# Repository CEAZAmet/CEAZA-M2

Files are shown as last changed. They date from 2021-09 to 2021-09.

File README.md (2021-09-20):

# Welcome to CEAZA-M2!
Prototyping board for CEAZA MEGA system.
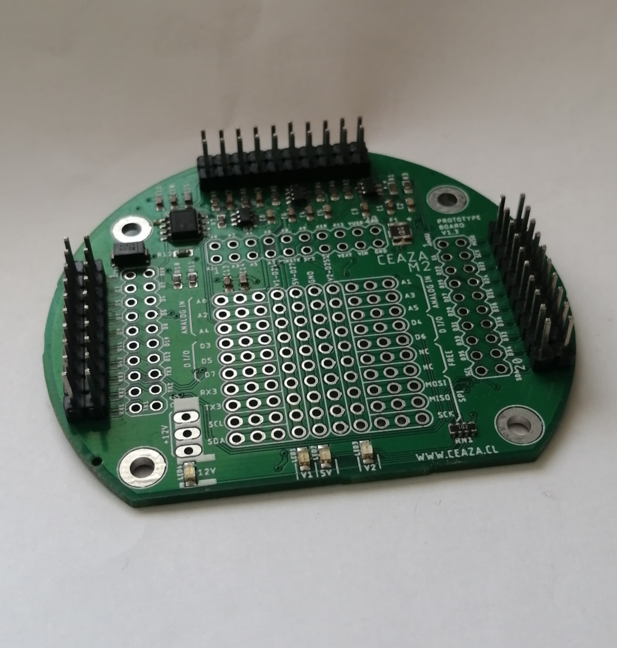
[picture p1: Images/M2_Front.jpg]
CEAZA M2 Board


# What is the CEAZA-M2?
Is a prototyping board with a firmware controlled +5V dedicated step-down power supply and controlled Vin pin for CEAZA MEGA system.
The board give you access to some pins as a PCB breadboard format, ready to solder any module or device.
Furthermore the board have a duplicate I/O expansion terminals to give you direct access to any of its pins.
Whith CEAZA M2 board you can easyly integrate any device to CEAZA MEGA system without any other customized board.

## Documentation
A comprehensive documentation for well undertand, use or modify the CEAZA M2 board is available in our Wiki. In adition, we share with you the schematics diagrams, adns Arduino example codes.

## Quickstart guide
Plan your electronic conection to your device, solder the necesay wires to connect your devices in the M2 board.
Install the M2 board in the CEAZA MEGA's bottom, make certain connection throuhg the boards by three 2 x 10 pin header terminals is rigth. Plug the battery and solar panel cables in the respective board terminal. be careful to avoid swap both plugs, due they are the same type of terminals. Connect the CEAZA MEGA main board system to the host PC by mini-USB connector, open the Arduino ide software, select the Arduino Mega board and the correspondign COM port.
Open any of examples scketches and upload to the board.
### WARNING!
Be careful with your breadboard conections due exist a posibility of a shortcircuit of the power supply acces in the breadboard. 
A 1A PTC Resettable fuse is placed in the main electric supply to the board (VIN pin od I/O expansion terminal) for extra electric protection.

# Contact and support
For all kinds of inquiries, please contact me to my e-mail address: adrian.gallardo@ceaza.cl

# Contributing
You are welcome to contribute to the development or improvement of M2 hardware design or example application codes. Feel free to submit a new pull request via github.

# Academic Context

# Licensing

# Disclaimer
Use M2 board and examples code at your own risk. We do not encourage any malicious use of our board.

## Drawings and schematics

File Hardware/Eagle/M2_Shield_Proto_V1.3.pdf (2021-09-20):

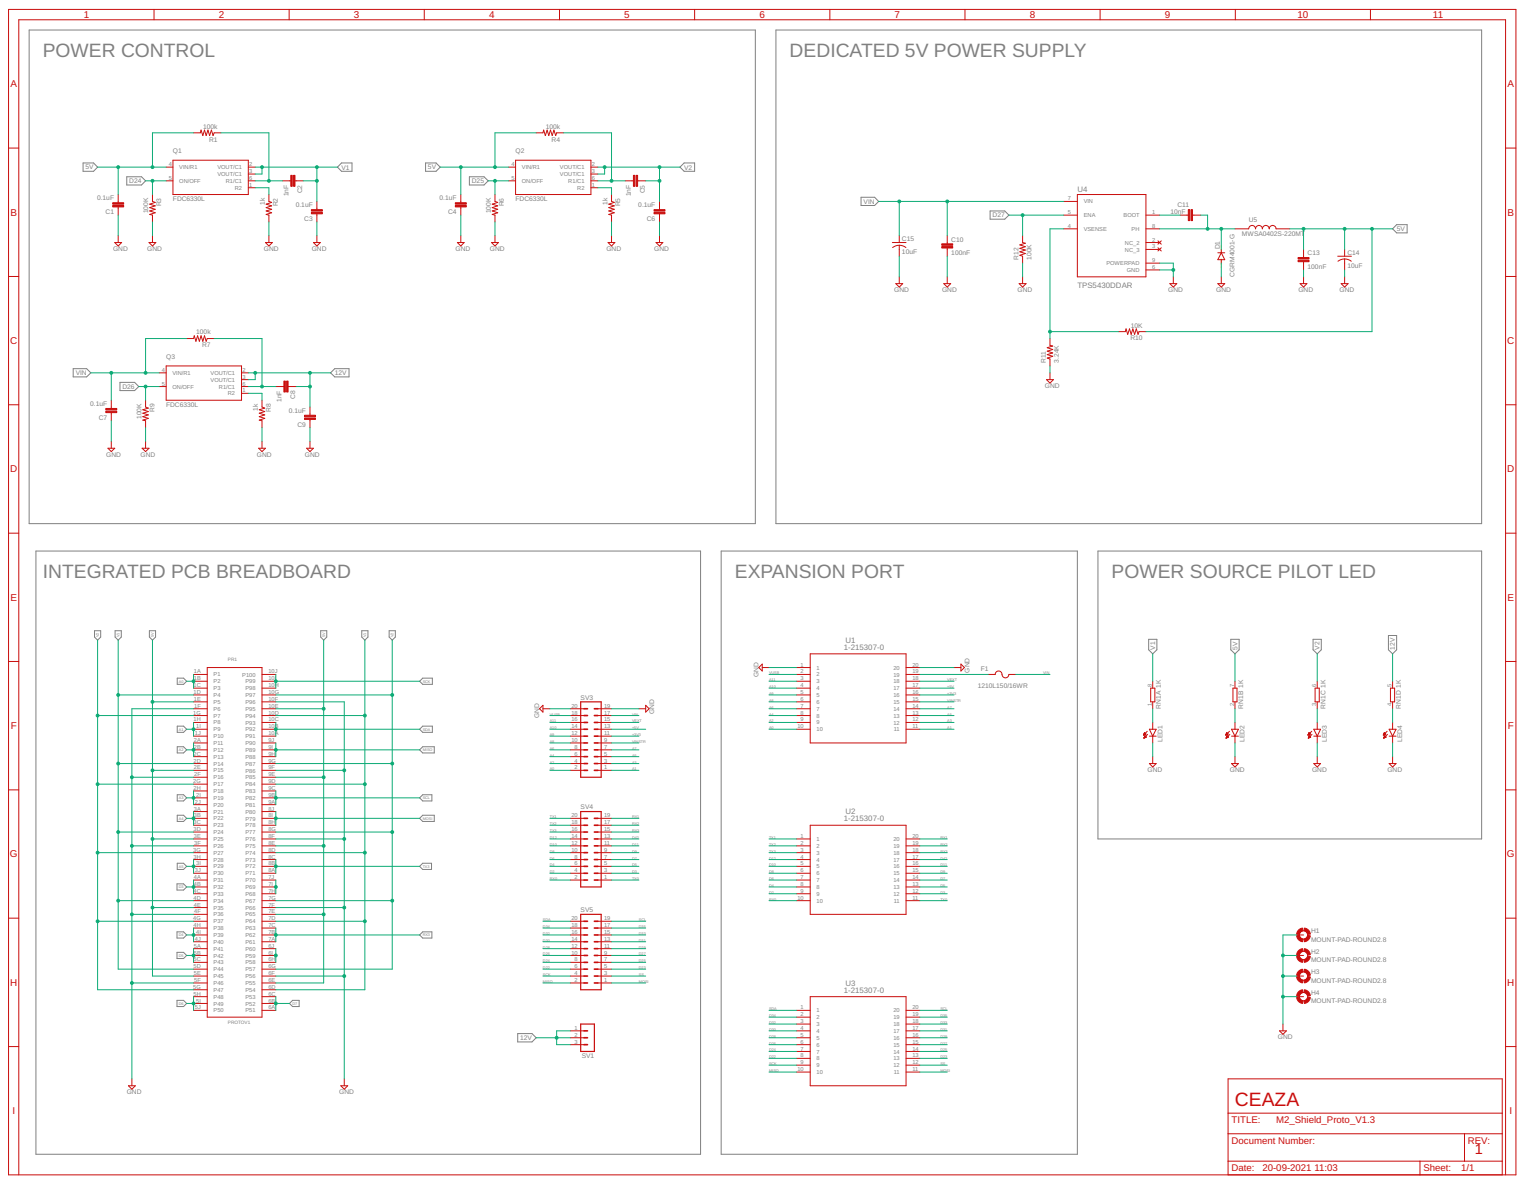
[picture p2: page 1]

MOUNT-PAD-ROUND2.8 MOUNT-PAD-ROUND2.8

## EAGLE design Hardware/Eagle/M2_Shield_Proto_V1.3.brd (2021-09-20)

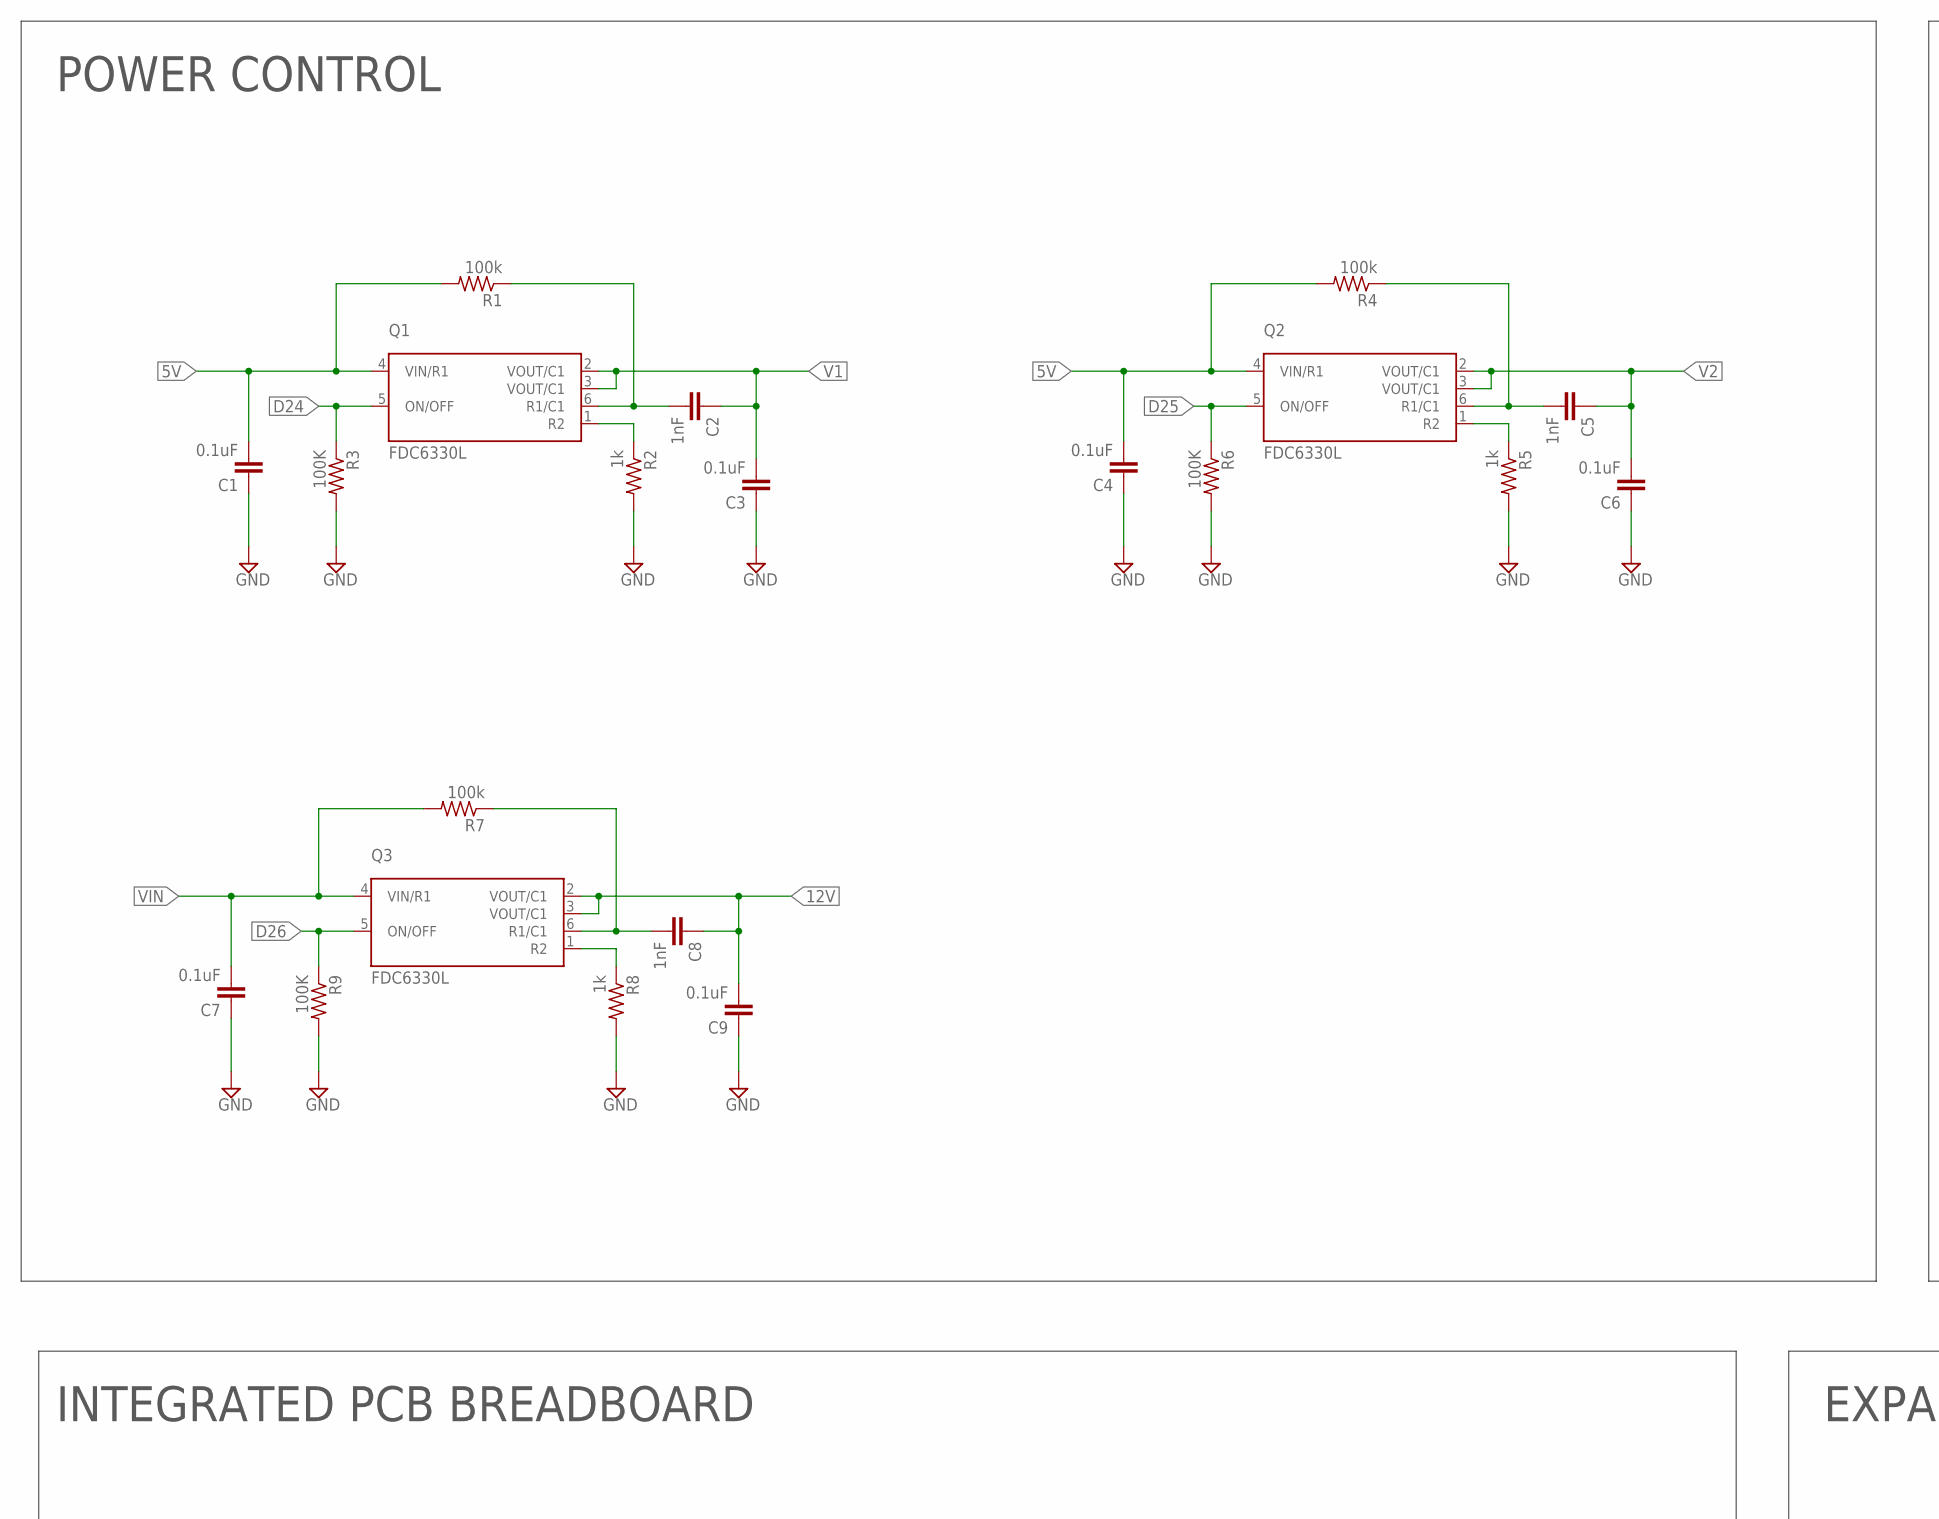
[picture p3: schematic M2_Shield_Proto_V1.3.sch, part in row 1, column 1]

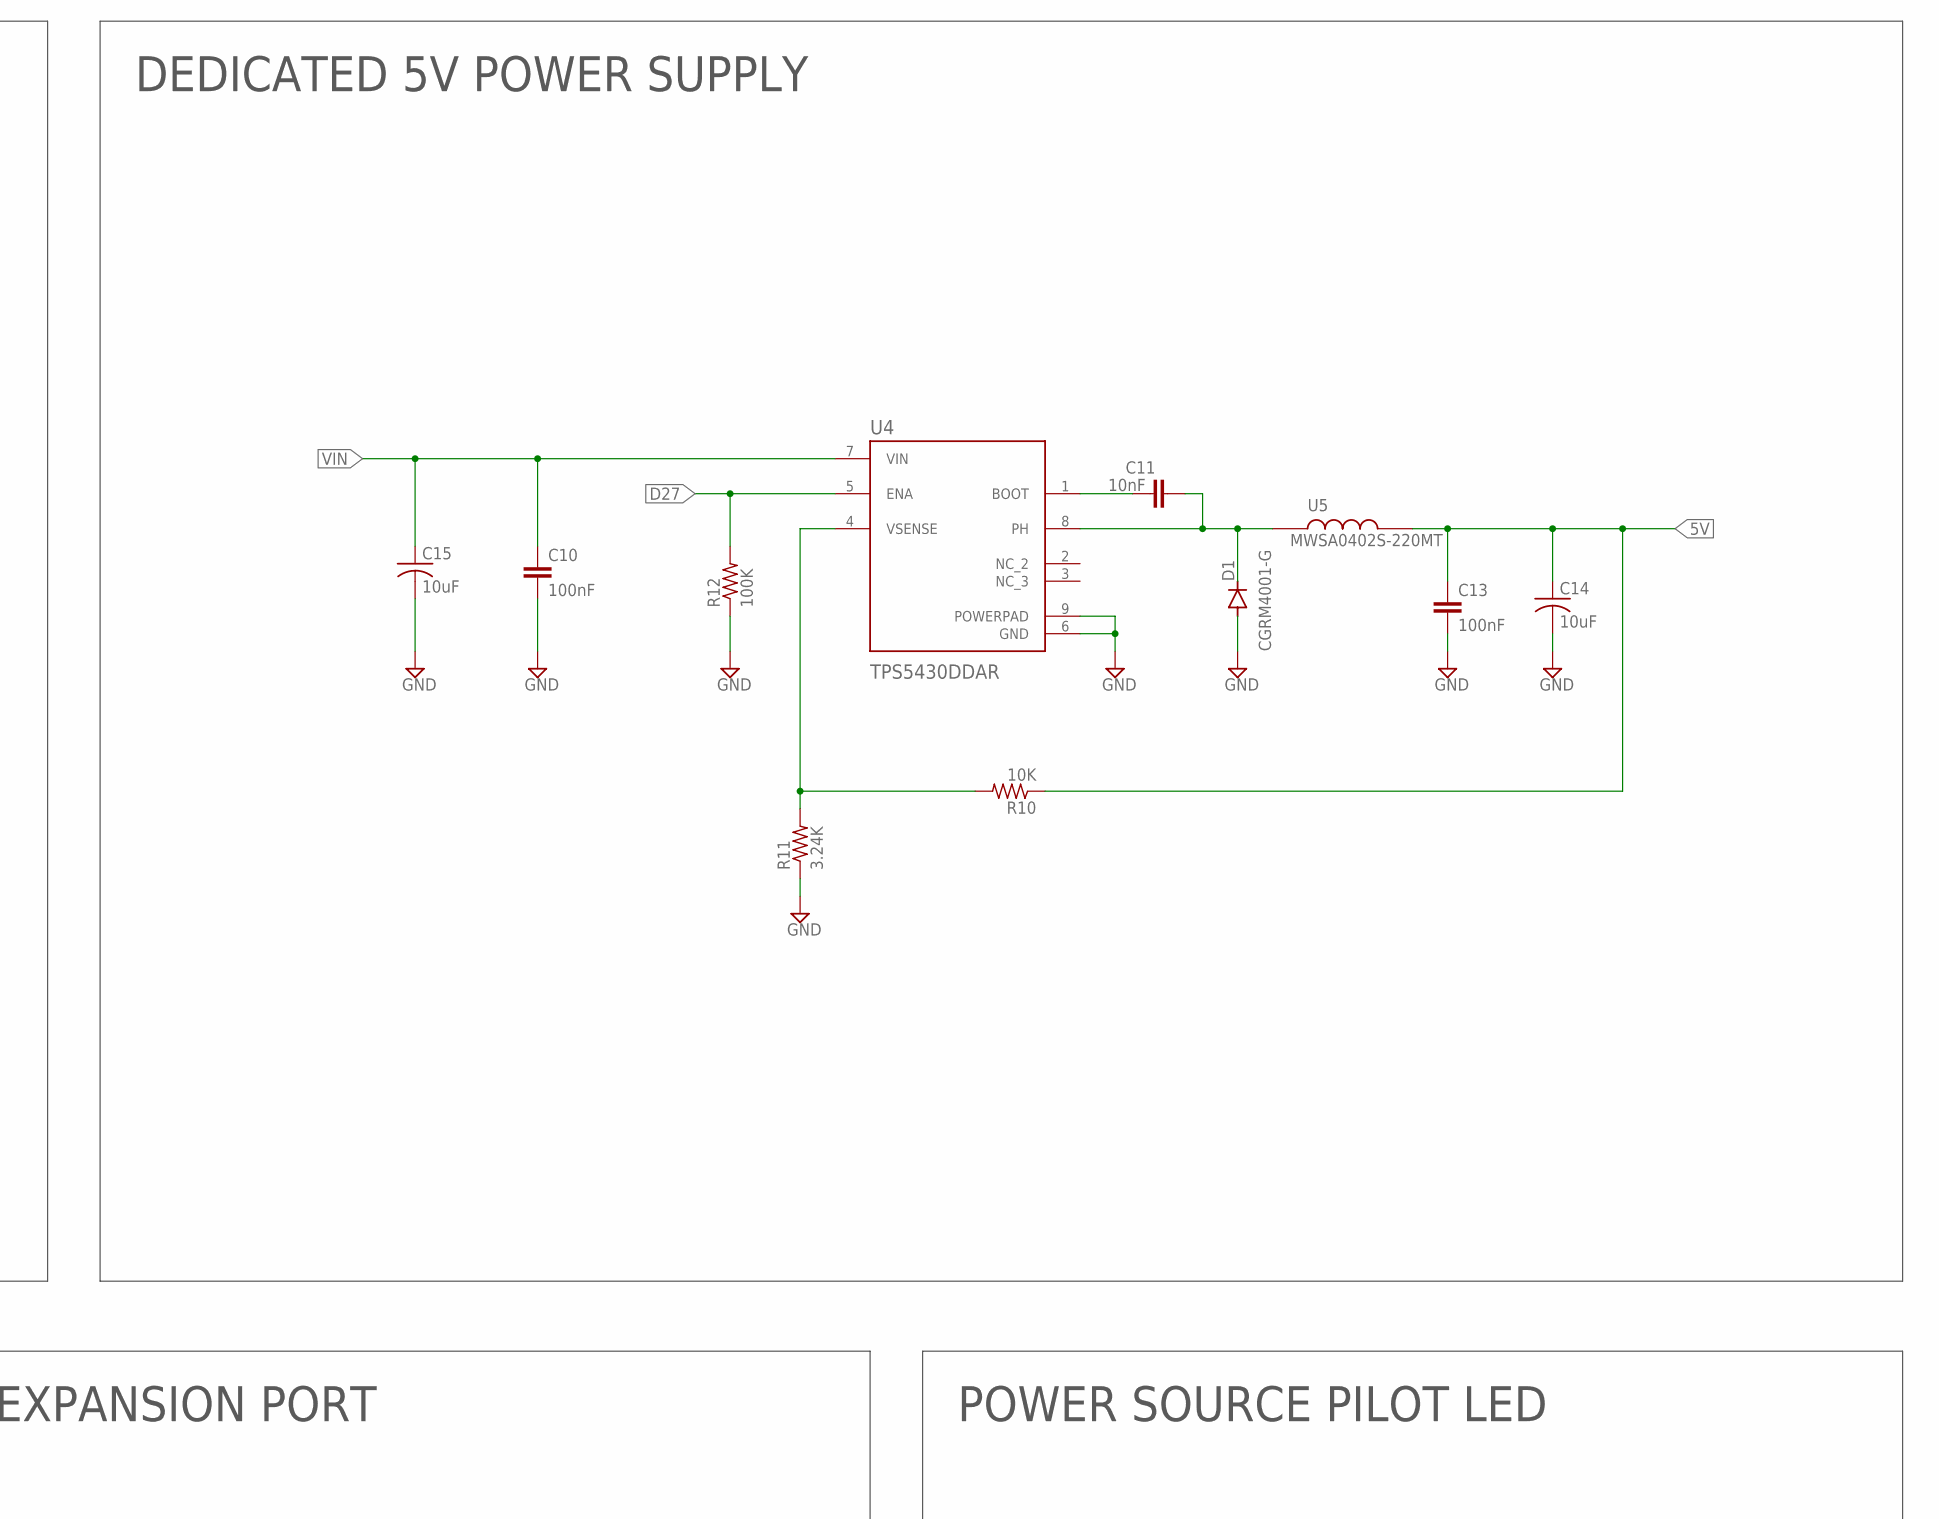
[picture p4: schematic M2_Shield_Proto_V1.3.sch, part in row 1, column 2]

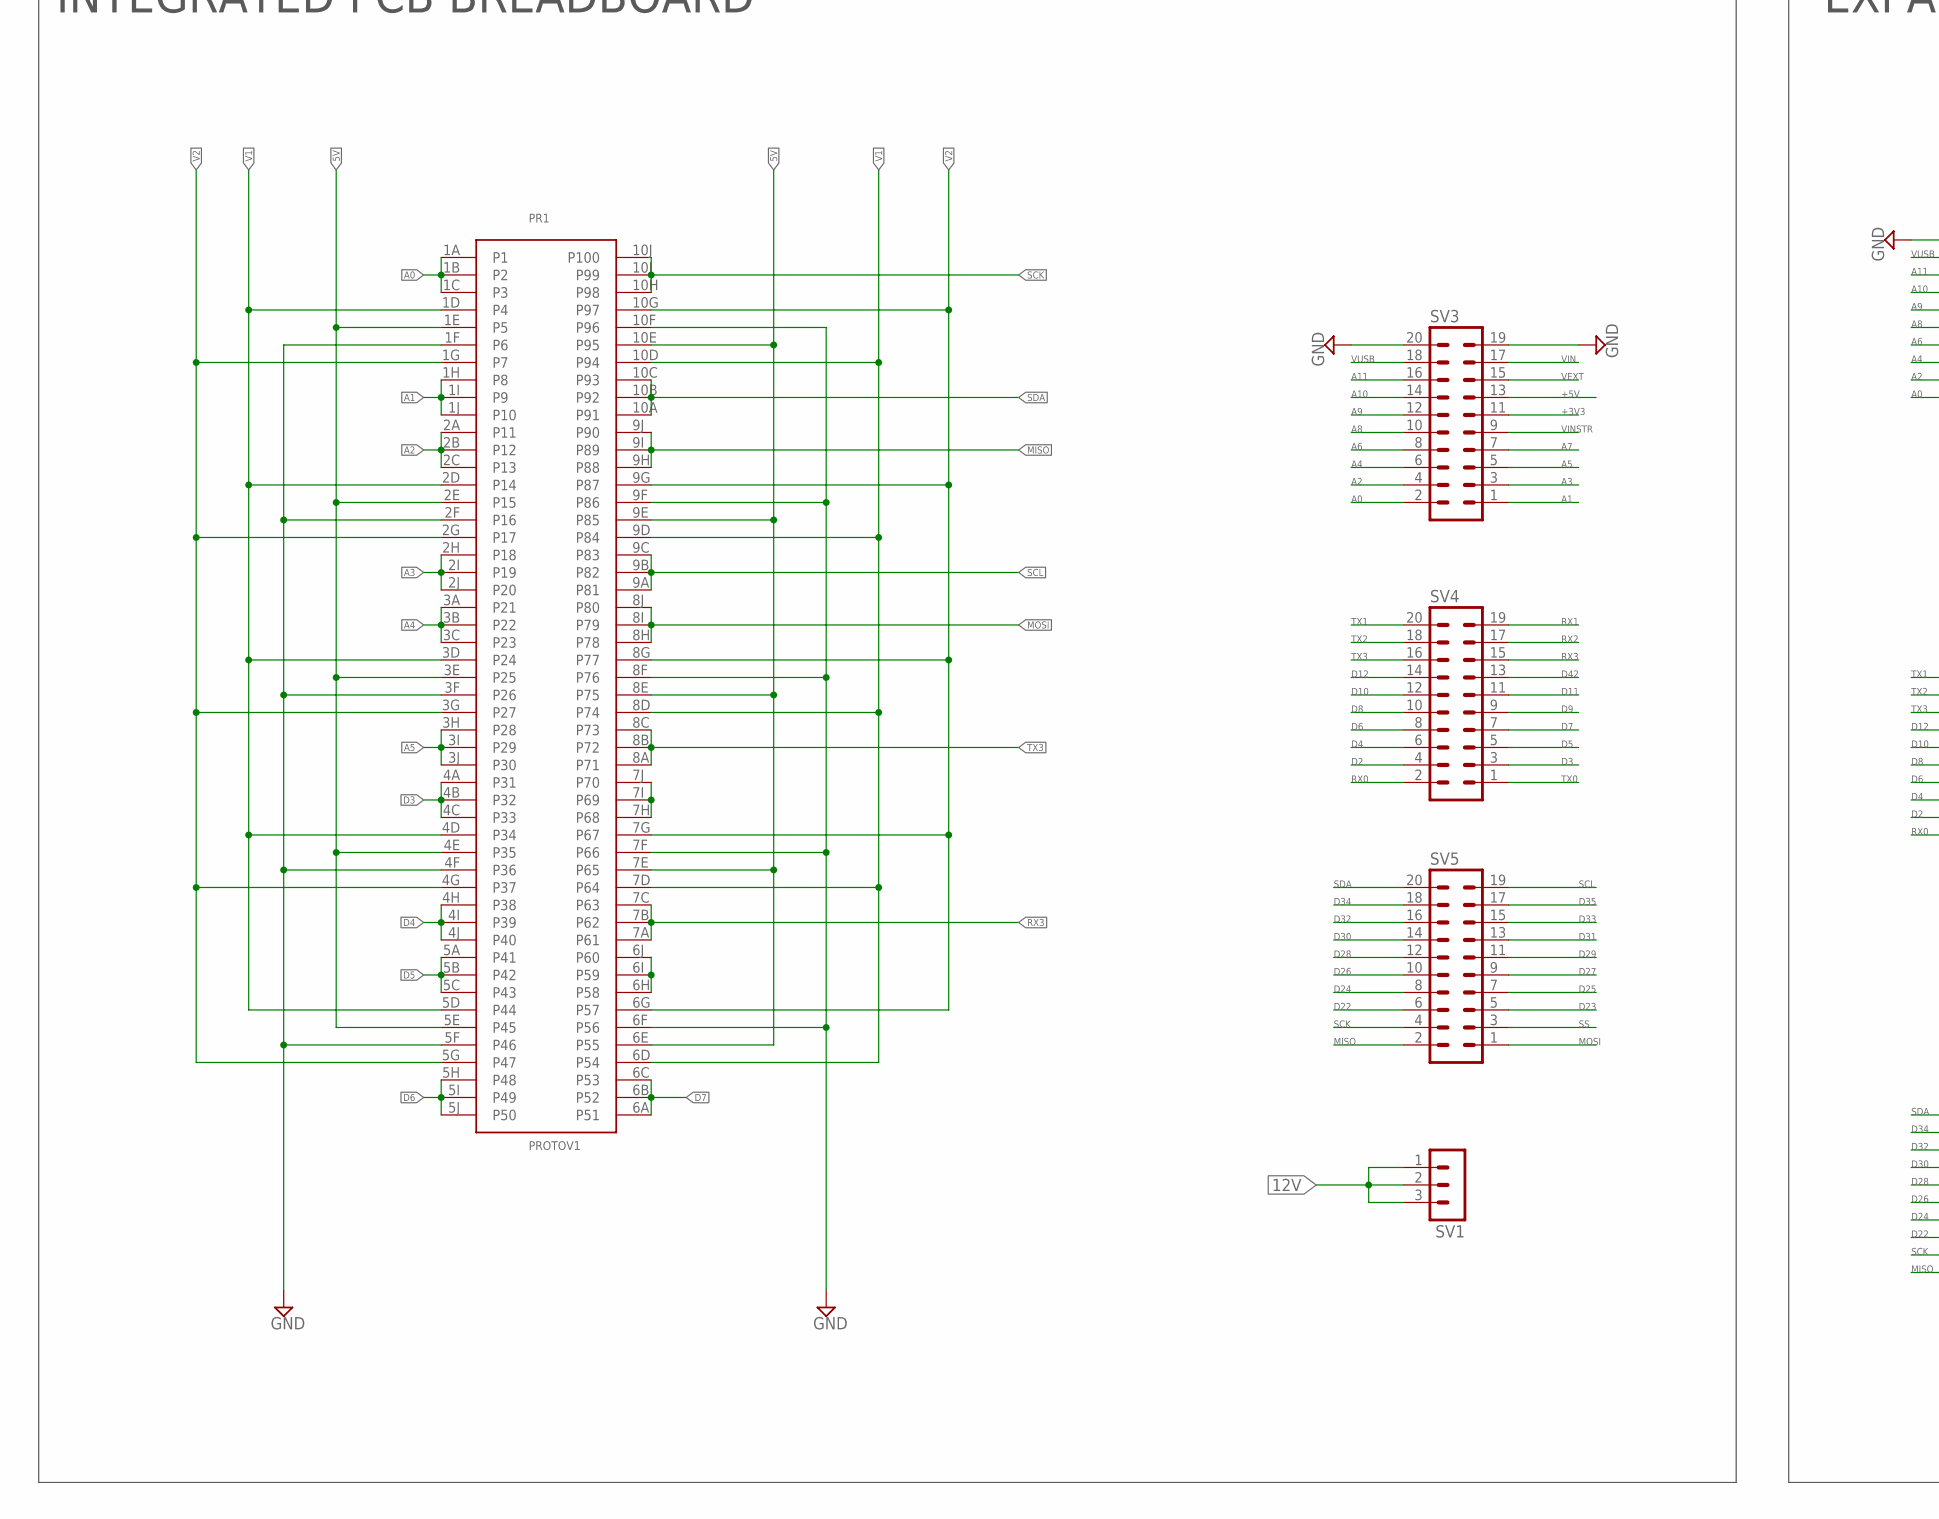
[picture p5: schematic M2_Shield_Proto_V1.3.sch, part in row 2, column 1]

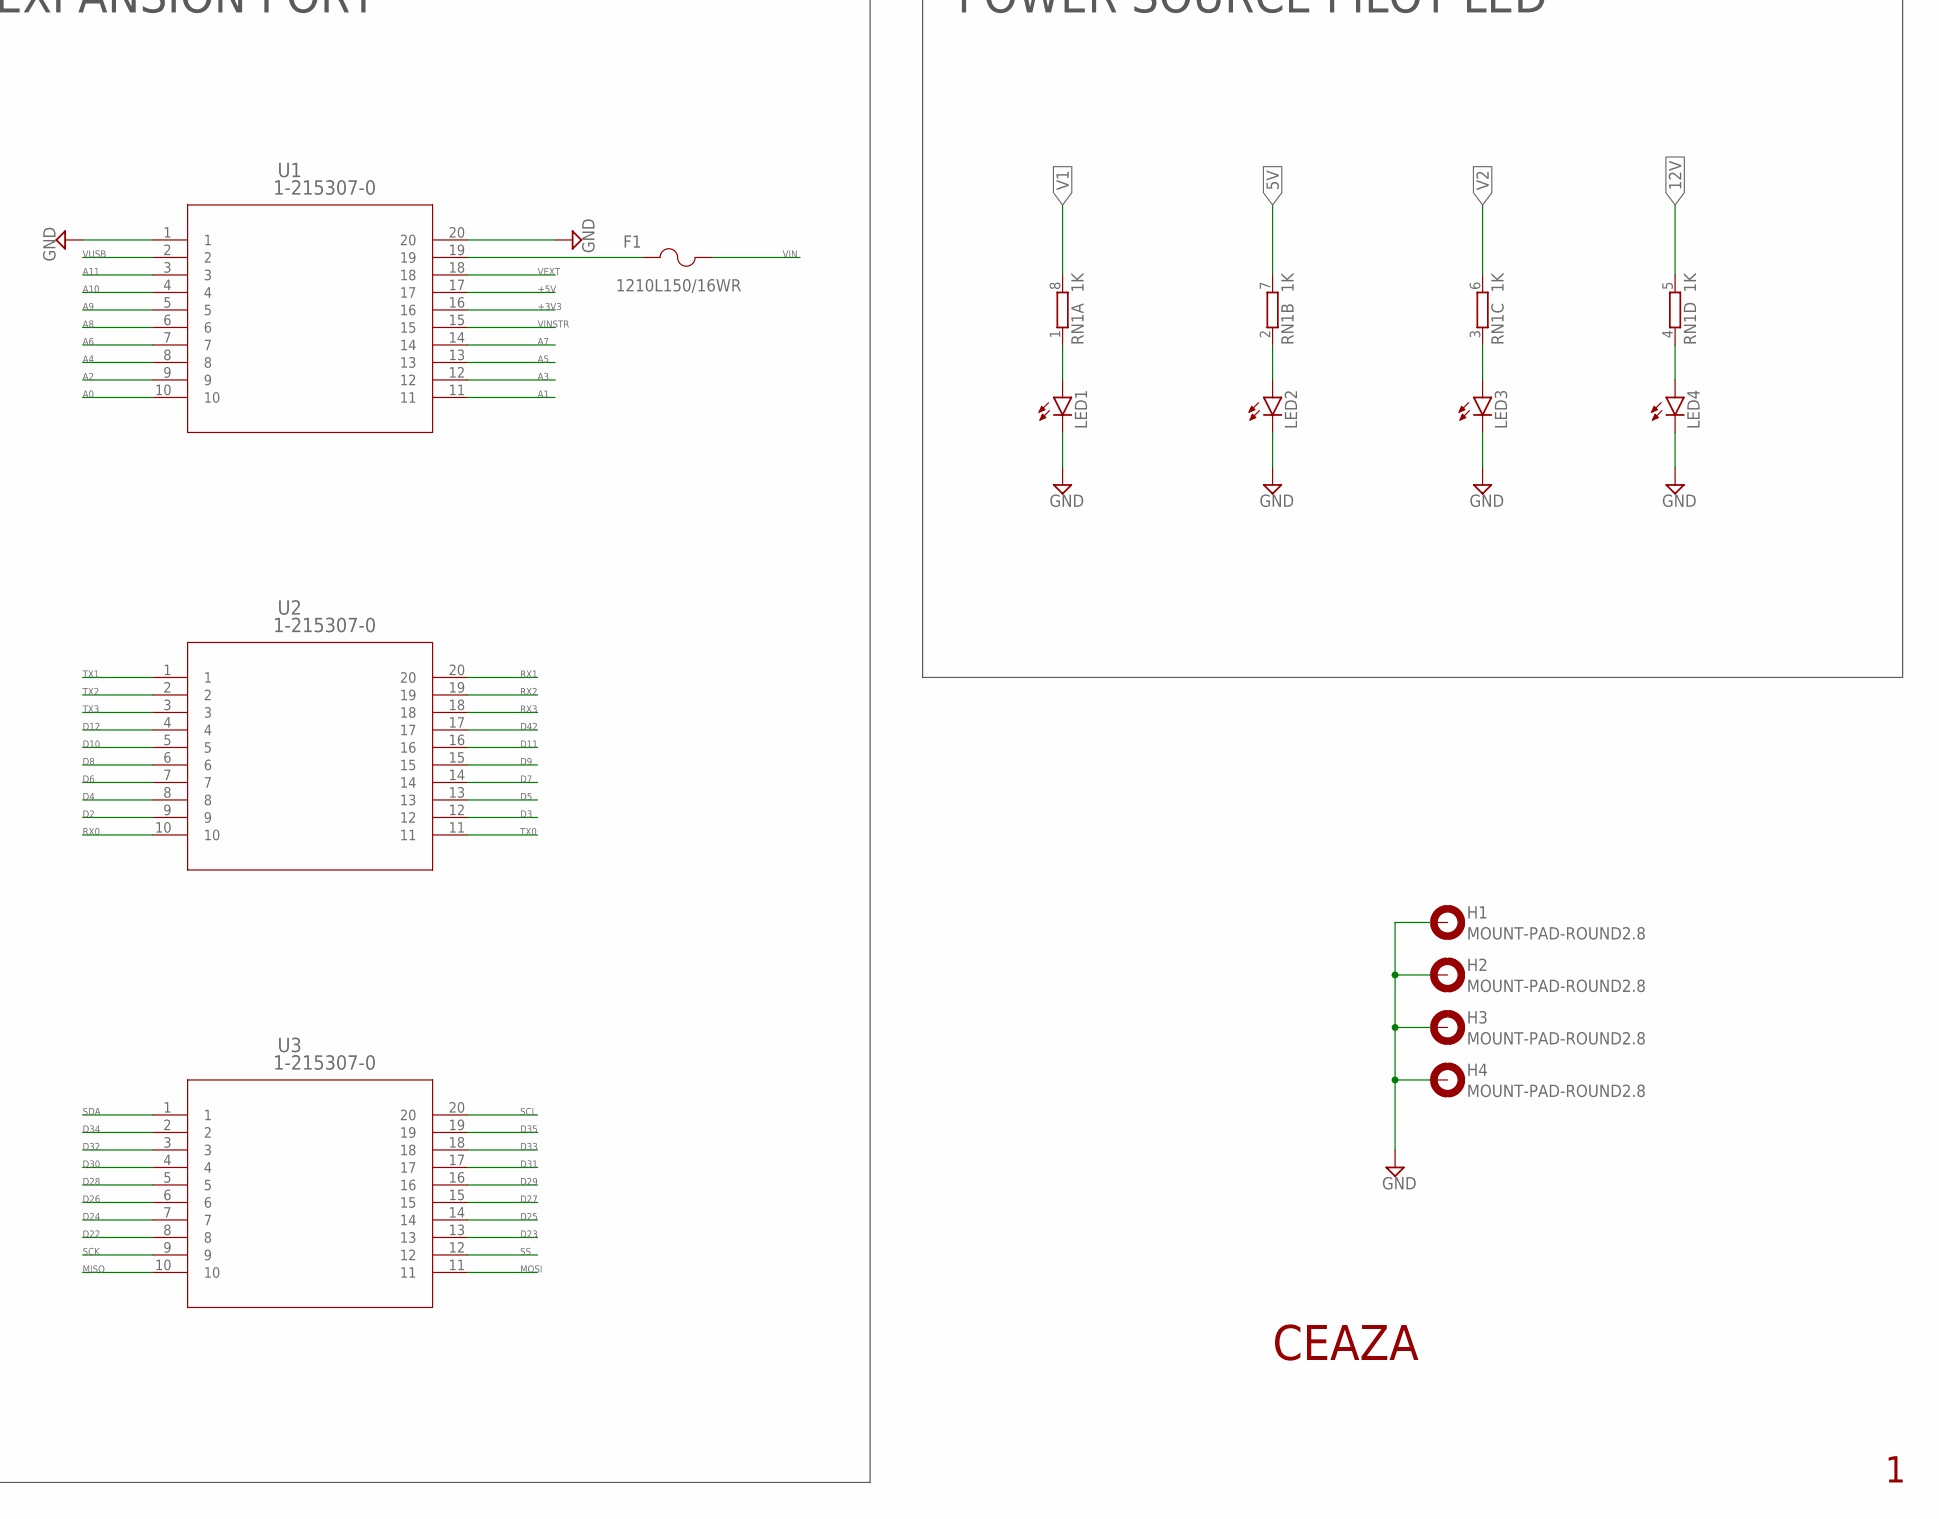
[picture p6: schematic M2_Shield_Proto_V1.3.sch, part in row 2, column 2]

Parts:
C1, C3, C4, C6, C7, C9: 0.1uF; C0603
C2, C5, C8: 1nF; C0603
C10, C13: 100nF; C0603
C11: 10nF; C0603
C14, C15: 10uF; C0603
D1: CGRM4001-G; SOD-123_MINI-SMA
F1: 1210L150/16WR; 1210LSERIES
H1, H2, H3, H4: MOUNT-PAD-ROUND2.8; 2,8-PAD
LED1, LED2, LED3, LED4: LEDCHIP-LED0805; CHIP-LED0805
PR1: PROTOV1
Q1, Q2, Q3: FDC6330L; SOT95P280X110-6N
R1, R4, R7: 100k; R0603
R2, R5, R8: 1k; R0603
R3, R6, R9, R12: 100K; R0603
R10: 10K; R0603
R11: 3.24K; R0603
RN1: 1K; 0603-ARV
SV1: MA03-1
SV3, SV4, SV5: MA10-2
U1, U2, U3: 1-215307-0
U4: TPS5430DDAR; CONV_TPS5430DDAR
U5: MWSA0402S-220MT

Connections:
5V: C1.2, C4.2, C13.1, C14.1, PR1.1E (P5), PR1.2E (P15), PR1.3E (P25), PR1.4E (P35), PR1.5E (P45), PR1.6E (P55), PR1.7E (P65), PR1.8E (P75), PR1.9E (P85), PR1.10E (P95), Q1.4 (VIN/R1), Q2.4 (VIN/R1), R1.2, R4.2, R10.1, RN1.7 (2), U5.P$2
12V: C8.1, C9.2, Q3.2 (VOUT/C1), Q3.3 (VOUT/C1), RN1.5 (2), SV1.1, SV1.2, SV1.3
+3V3: SV3.11, U1.16
+5V: SV3.13, U1.17
A0: PR1.1A (P1), PR1.1B (P2), PR1.1C (P3), SV3.2, U1.10
A1: PR1.1H (P8), PR1.1I (P9), PR1.1J (P10), SV3.1, U1.11
A2: PR1.2A (P11), PR1.2B (P12), PR1.2C (P13), SV3.4, U1.9
A3: PR1.2H (P18), PR1.2I (P19), PR1.2J (P20), SV3.3, U1.12
A4: PR1.3A (P21), PR1.3B (P22), PR1.3C (P23), SV3.6, U1.8
A5: PR1.3H (P28), PR1.3I (P29), PR1.3J (P30), SV3.5, U1.13
A6: SV3.8, U1.7
A7: SV3.7, U1.14
A8: SV3.10, U1.6
A9: SV3.12, U1.5
A10: SV3.14, U1.4
A11: SV3.16, U1.3
D2: SV4.4, U2.9
D3: PR1.4A (P31), PR1.4B (P32), PR1.4C (P33), SV4.3, U2.12
D4: PR1.4H (P38), PR1.4I (P39), PR1.4J (P40), SV4.6, U2.8
D5: PR1.5A (P41), PR1.5B (P42), PR1.5C (P43), SV4.5, U2.13
D6: PR1.5H (P48), PR1.5I (P49), PR1.5J (P50), SV4.8, U2.7
D7: PR1.6A (P51), PR1.6B (P52), PR1.6C (P53), SV4.7, U2.14
D8: SV4.10, U2.6
D9: SV4.9, U2.15
D10: SV4.12, U2.5
D11: SV4.11, U2.16
D12: SV4.14, U2.4
D22: SV5.6, U3.8
D23: SV5.5, U3.13
D24: Q1.5 (ON/OFF), R3.1, SV5.8, U3.7
D25: Q2.5 (ON/OFF), R6.1, SV5.7, U3.14
D26: Q3.5 (ON/OFF), R9.1, SV5.10, U3.6
D27: R12.2, SV5.9, U3.15, U4.5 (ENA)
D28: SV5.12, U3.5
D29: SV5.11, U3.16
D30: SV5.14, U3.4
D31: SV5.13, U3.17
D32: SV5.16, U3.3
D33: SV5.15, U3.18
D34: SV5.18, U3.2
D35: SV5.17, U3.19
D42: SV4.13, U2.17
GND: C1.1, C3.1, C4.1, C6.1, C7.1, C9.1, C10.2, C13.2, C14.2, C15.2, D1.A, H1.B2,8, H2.B2,8, H3.B2,8, H4.B2,8, LED1.C, LED2.C, LED3.C, LED4.C, PR1.1F (P6), PR1.2F (P16), PR1.3F (P26), PR1.4F (P36), PR1.5F (P46), PR1.6F (P56), PR1.7F (P66), PR1.8F (P76), PR1.9F (P86), PR1.10F (P96), R2.2, R3.2, R5.2, R6.2, R8.2, R9.2, R11.1, R12.1, SV3.19, SV3.20, U1.1, U1.20, U4.6 (GND), U4.9 (POWERPAD)
MISO: PR1.9H (P88), PR1.9I (P89), PR1.9J (P90), SV5.2, U3.10
MOSI: PR1.8H (P78), PR1.8I (P79), PR1.8J (P80), SV5.1, U3.11
unnamed: C11.1, U4.1 (BOOT)
unnamed: LED1.A, RN1.1
unnamed: LED2.A, RN1.2 (1)
unnamed: LED3.A, RN1.3 (1)
unnamed: LED4.A, RN1.4 (1)
unnamed: C11.2, D1.C, U4.8 (PH), U5.P$1
unnamed: C2.2, Q1.6 (R1/C1), R1.1
unnamed: Q1.1 (R2), R2.1
unnamed: C5.2, Q2.6 (R1/C1), R4.1
unnamed: Q2.1 (R2), R5.1
unnamed: PR1.6H (P58), PR1.6I (P59), PR1.6J (P60)
unnamed: PR1.7H (P68), PR1.7I (P69), PR1.7J (P70)
unnamed: R10.2, R11.2, U4.4 (VSENSE)
unnamed: C8.2, Q3.6 (R1/C1), R7.1
unnamed: Q3.1 (R2), R8.1
unnamed: F1.1, U1.19
RX0: SV4.2, U2.10
RX1: SV4.19, U2.20
RX2: SV4.17, U2.19
RX3: PR1.7A (P61), PR1.7B (P62), PR1.7C (P63), SV4.15, U2.18
SCK: PR1.10H (P98), PR1.10I (P99), PR1.10J (P100), SV5.4, U3.9
SCL: PR1.9A (P81), PR1.9B (P82), PR1.9C (P83), SV5.19, U3.20
SDA: PR1.10A (P91), PR1.10B (P92), PR1.10C (P93), SV5.20, U3.1
SS: SV5.3, U3.12
TX0: SV4.1, U2.11
TX1: SV4.20, U2.1
TX2: SV4.18, U2.2
TX3: PR1.8A (P71), PR1.8B (P72), PR1.8C (P73), SV4.16, U2.3
V1: C2.1, C3.2, PR1.1D (P4), PR1.2D (P14), PR1.3D (P24), PR1.4D (P34), PR1.5D (P44), PR1.6D (P54), PR1.7D (P64), PR1.8D (P74), PR1.9D (P84), PR1.10D (P94), Q1.2 (VOUT/C1), Q1.3 (VOUT/C1), RN1.8 (2)
V2: C5.1, C6.2, PR1.1G (P7), PR1.2G (P17), PR1.3G (P27), PR1.4G (P37), PR1.5G (P47), PR1.6G (P57), PR1.7G (P67), PR1.8G (P77), PR1.9G (P87), PR1.10G (P97), Q2.2 (VOUT/C1), Q2.3 (VOUT/C1), RN1.6 (2)
VEXT: SV3.15, U1.18
VIN: C7.2, C10.1, C15.1, F1.2, Q3.4 (VIN/R1), R7.2, SV3.17, U4.7 (VIN)
VINSTR: SV3.9, U1.15
VUSB: SV3.18, U1.2

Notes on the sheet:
DEDICATED 5V POWER SUPPLY
POWER CONTROL
INTEGRATED PCB BREADBOARD
EXPANSION PORT
POWER SOURCE PILOT LED
CEAZA

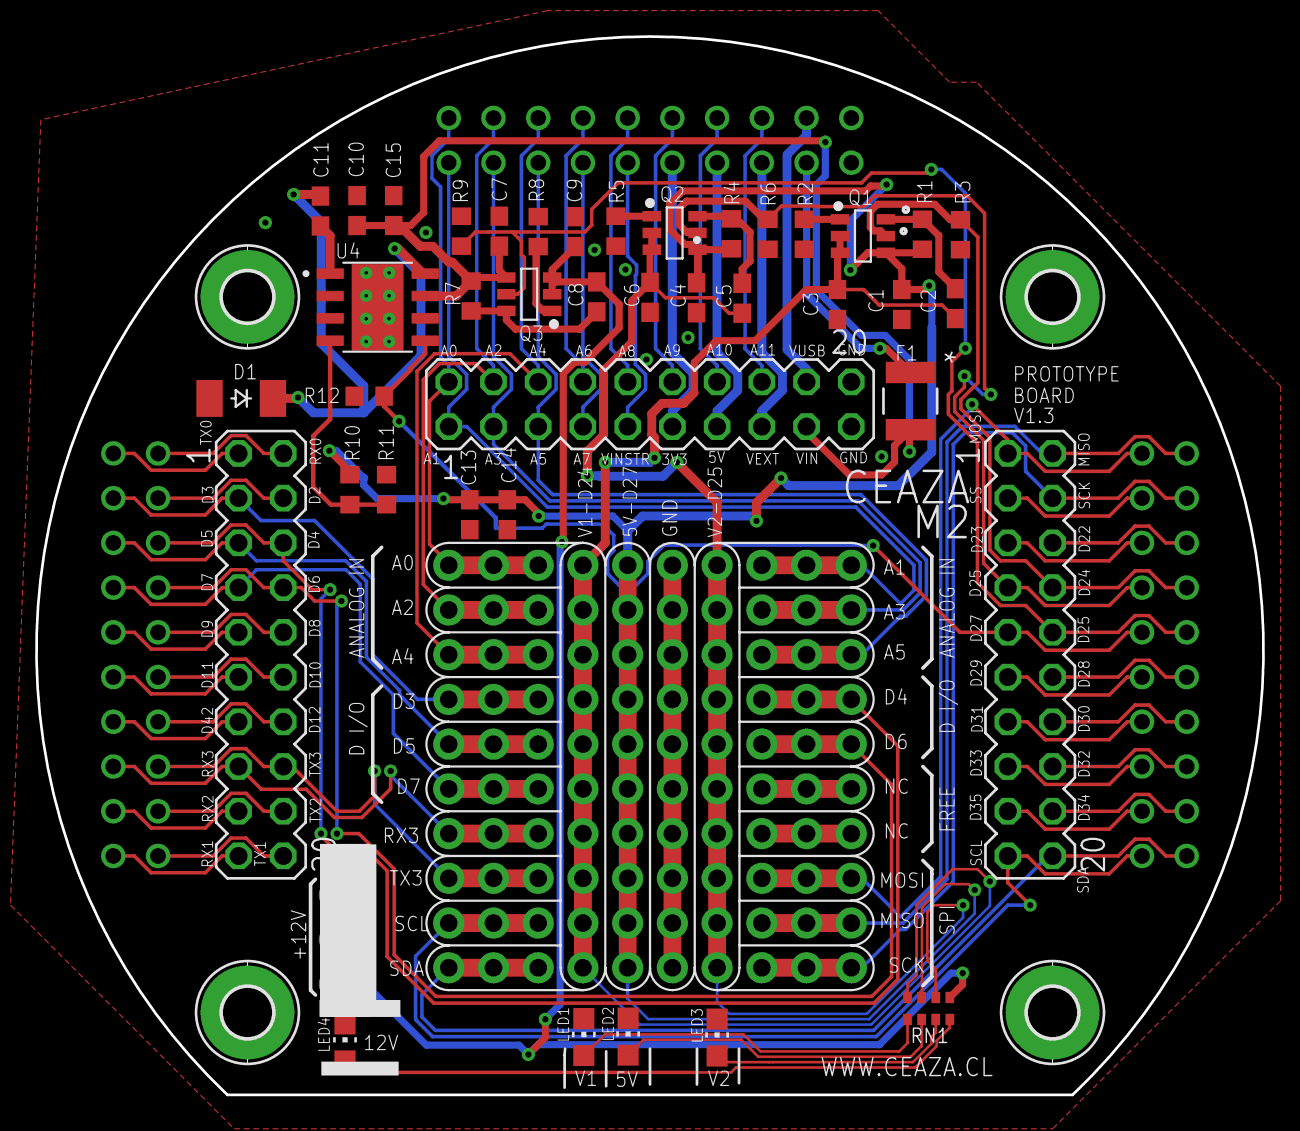
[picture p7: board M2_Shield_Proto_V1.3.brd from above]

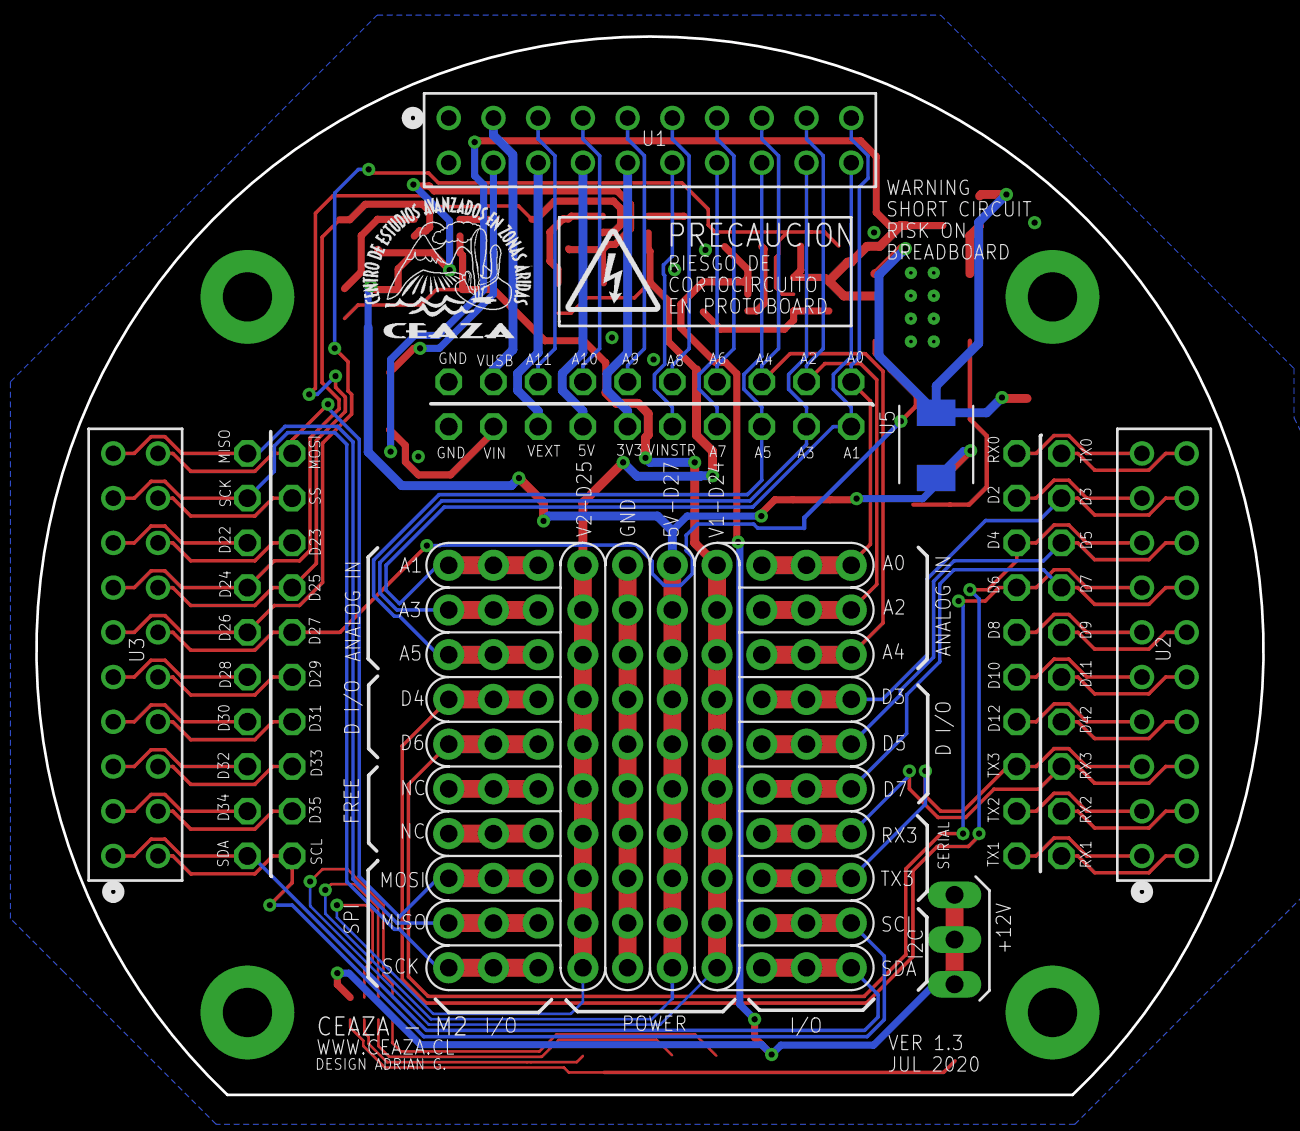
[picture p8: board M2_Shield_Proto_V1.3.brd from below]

Board: 2 copper layers, 69.7 x 60.1 mm, 50 parts (4 on the bottom side), 79 nets.

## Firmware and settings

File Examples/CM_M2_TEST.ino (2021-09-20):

/*
 * This sketch shows how to activate or deactivate the power sources available in
 * CEAZA M2 board for CEAZA MEGA systrem through a LED power pilot on/off pattern.
 * M2 board have 4 firmware controlled power nodes for precise energy management aplications.
 * The power nodes are:
 * - SW/VIN: Is a controlled Vin terminal form connected devices over 5V supply
 * - SW/+5V: Is a dc-dc stepdown converter wich can deliver up to 3A
 * - SW/V1:  Is a controlled SW/+5V terminal wich can deliver up to 2A. If you need to activate V1 you must activate SW/+5V before
 * - SW/V2:  Is a second controlled SW/+5V terminal wich can deliver up to 2A. If you need to activate V2 you must activate SW/+5V before
 */
#define M2_5V_EN_PIN 27
#define M2_V1_EN_PIN 24
#define M2_V2_EN_PIN 25
#define M2_VIN_EN_PIN 26

void setup() {
  // M2 power controller pins setup
  pinMode(M2_5V_EN_PIN,OUTPUT);digitalWrite(M2_5V_EN_PIN,LOW);
  pinMode(M2_V1_EN_PIN,OUTPUT);digitalWrite(M2_V1_EN_PIN,LOW);
  pinMode(M2_V2_EN_PIN,OUTPUT);digitalWrite(M2_V2_EN_PIN,LOW);
  pinMode(M2_VIN_EN_PIN,OUTPUT);digitalWrite(M2_VIN_EN_PIN,LOW);
}

void loop() {
  digitalWrite(M2_5V_EN_PIN,HIGH);    // Turn on 5V dc-dc step down power supply
  delay(500);
  digitalWrite(M2_V1_EN_PIN,HIGH);    // Turn on V1
  delay(500);
  digitalWrite(M2_V2_EN_PIN,HIGH);    // Turn on V2
  delay(500);
  digitalWrite(M2_VIN_EN_PIN,HIGH);   // Turn on SW/VIN
  delay(500);
  digitalWrite(M2_VIN_EN_PIN,LOW);    // Turn off SW/VIN
  digitalWrite(M2_V2_EN_PIN,LOW);     // Turn off V2
  digitalWrite(M2_V1_EN_PIN,LOW);     // Turn off V1
  digitalWrite(M2_5V_EN_PIN,LOW);     // Turn off 5V dc-dc step down power supply
  delay(500);
}
